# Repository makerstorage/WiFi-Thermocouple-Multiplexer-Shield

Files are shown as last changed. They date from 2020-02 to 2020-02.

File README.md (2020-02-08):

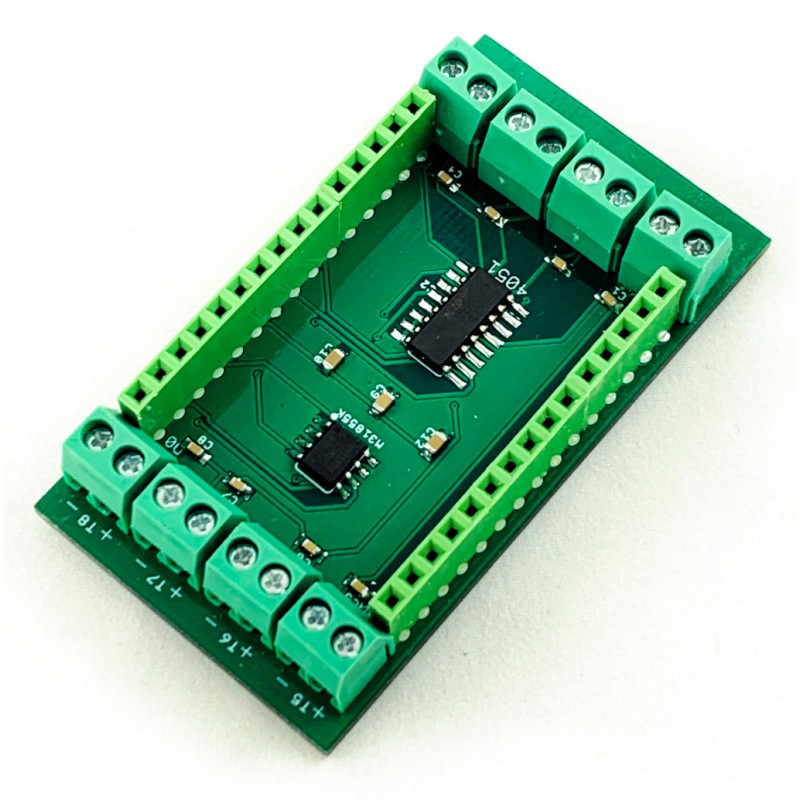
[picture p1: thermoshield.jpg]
WiFi Thermocouple Multiplexer Shield


**WiFi Thermocouple Multiplexer Shield**

For more details, check out the product page at

https://makerstorage.com/index.php?id_product=35&controller=product

MakerStorage invests time and resources providing this open source design, please support MakerStorage and open-source hardware by purchasing products from MakerStorage!

Designed by MakerStorage LLC.

Creative Commons Attribution, Share-Alike license, check https://creativecommons.org/licenses/by-sa/3.0/ for more information All text above must be included in any redistribution

This Shield is designed to easily allow multiple high-temperature readings with an ESP8266 control board. Screw terminals are provided for thermocouple connections.

* Multiplexing seven K-type thermocouples (Can read all sensors under a second)
* Wifi capability (example firmware for local server and Amazon AWS IoT)
* Suitable for only Lolin models of ESP8266 (27mm between headers)
* Onboard Max31855KASA  Cold-Junction Compensated Thermocouple-to-Digital Converter
* Works with K type thermocouples
-200°C to +1350°C output in 0.25 degree increments - note that K thermocouples have about ±2°C to ±6°C accuracy

**Areas to use:**

* Automotive – Engine, Exhaust and Brake temperatures

* Ovens, Furnaces, and Kilns

* Freezer or Cryogenic monitoring

* Chemical Processes

* IoT applications like Multi-Zone Temperature Monitoring, Data Acquisition or Logging Systems

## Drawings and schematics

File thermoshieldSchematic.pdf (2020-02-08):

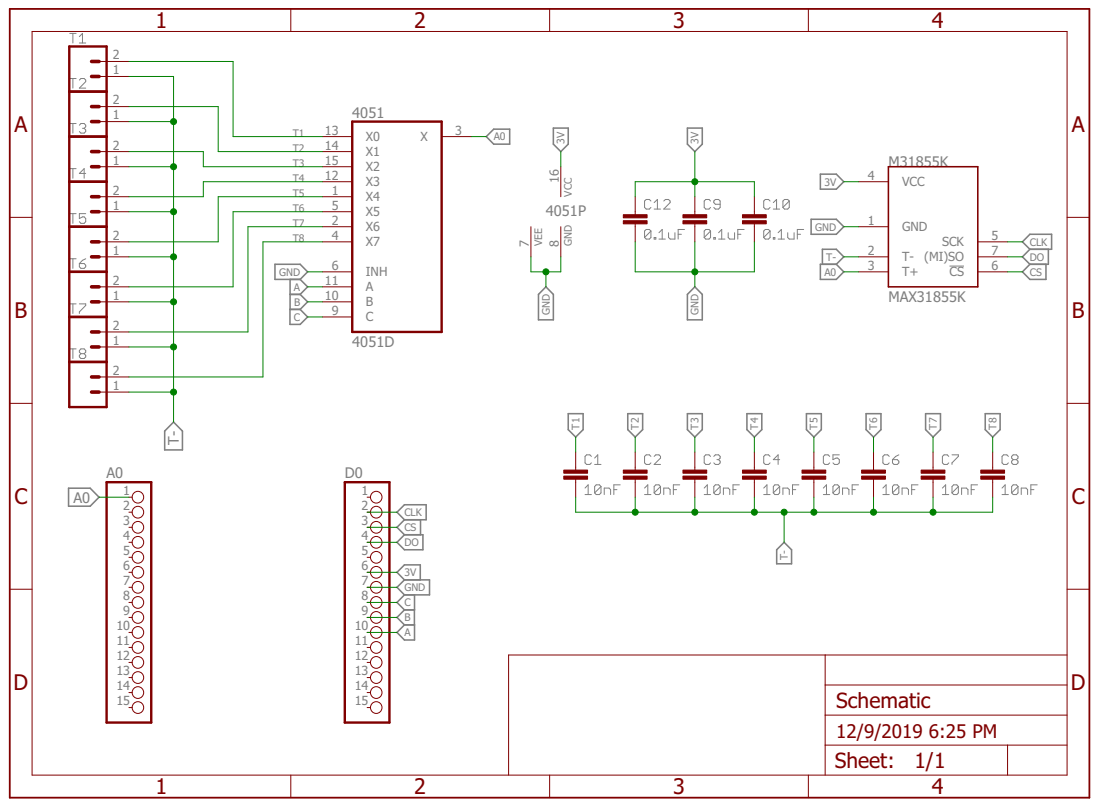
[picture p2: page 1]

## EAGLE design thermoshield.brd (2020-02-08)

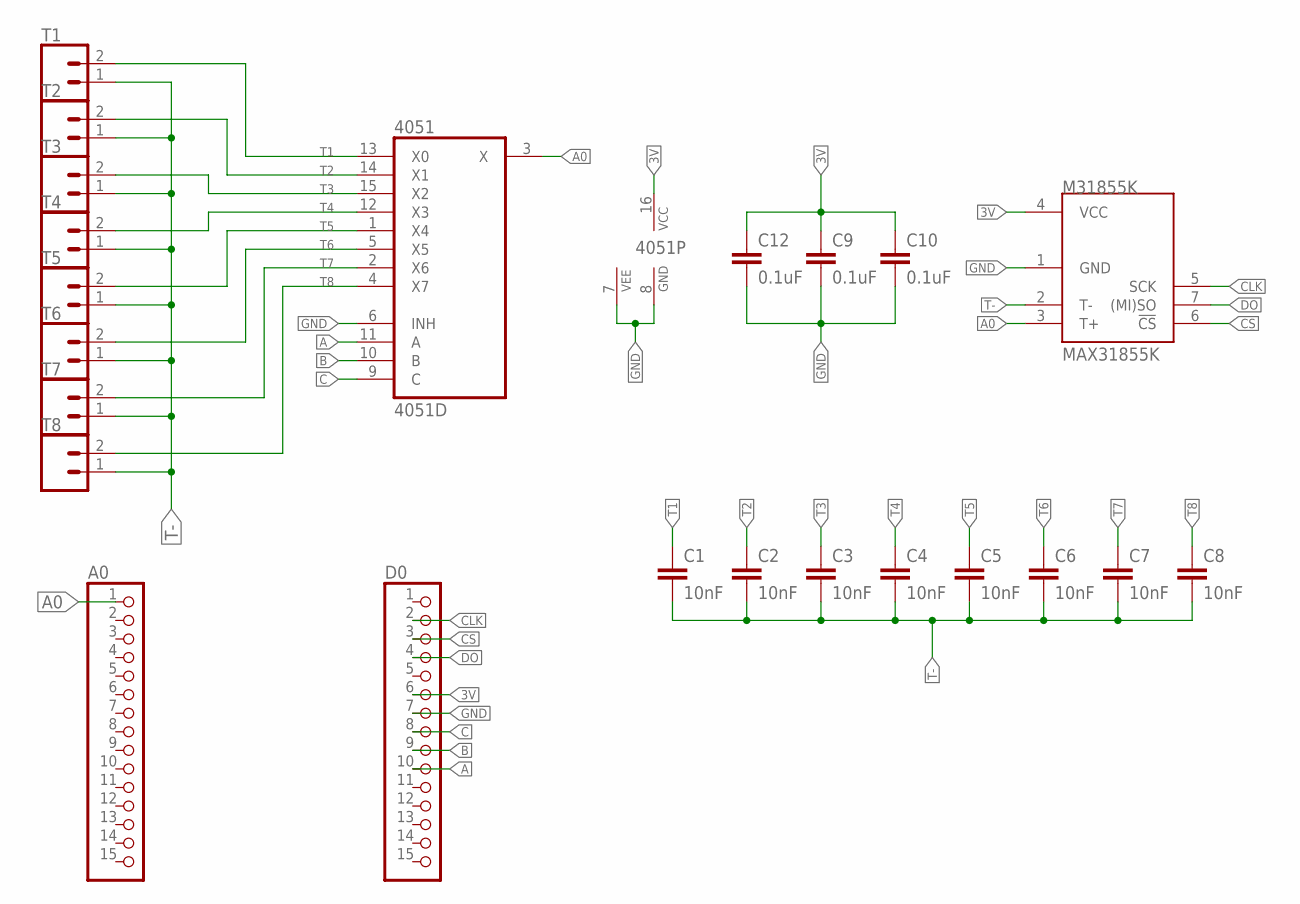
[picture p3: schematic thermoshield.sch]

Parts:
4051: 4051D; SO16
A0: PINHD-1X15; 1X15
C1, C2, C3, C4, C5, C6, C7, C8: 10nF; 0603
C9, C10, C12: 0.1uF; 0603
D0: PINHD-1X15; 1X15
M31855K: MAX31855K; SO08
T1, T2, T3, T4, T5, T6, T7, T8: CONN_023.5MM-NO_SILK; SCREWTERMINAL-3.5MM-2-NS

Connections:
3V: 4051.16 (VCC), C9.1, C10.1, C12.1, D0.6, M31855K.4 (VCC)
A: 4051.11 (A), D0.10
A0: 4051.3 (X), A0.1, M31855K.3 (T+)
B: 4051.10 (B), D0.9
C: 4051.9 (C), D0.8
CLK: D0.2, M31855K.5 (SCK)
CS: D0.3, M31855K.6 (!CS)
DO: D0.4, M31855K.7 ((MI)SO)
GND: 4051.6 (INH), 4051.7 (VEE), 4051.8 (GND), C9.2, C10.2, C12.2, D0.7, M31855K.1 (GND)
T1: 4051.13 (X0), C1.1, T1.2
T2: 4051.14 (X1), C2.1, T2.2
T3: 4051.15 (X2), C3.1, T3.2
T4: 4051.12 (X3), C4.1, T4.2
T5: 4051.1 (X4), C5.1, T5.2
T6: 4051.5 (X5), C6.1, T6.2
T7: 4051.2 (X6), C7.1, T7.2
T8: 4051.4 (X7), C8.1, T8.2
T-: C1.2, C2.2, C3.2, C4.2, C5.2, C6.2, C7.2, C8.2, M31855K.2 (T-), T1.1, T2.1, T3.1, T4.1, T5.1, T6.1, T7.1, T8.1

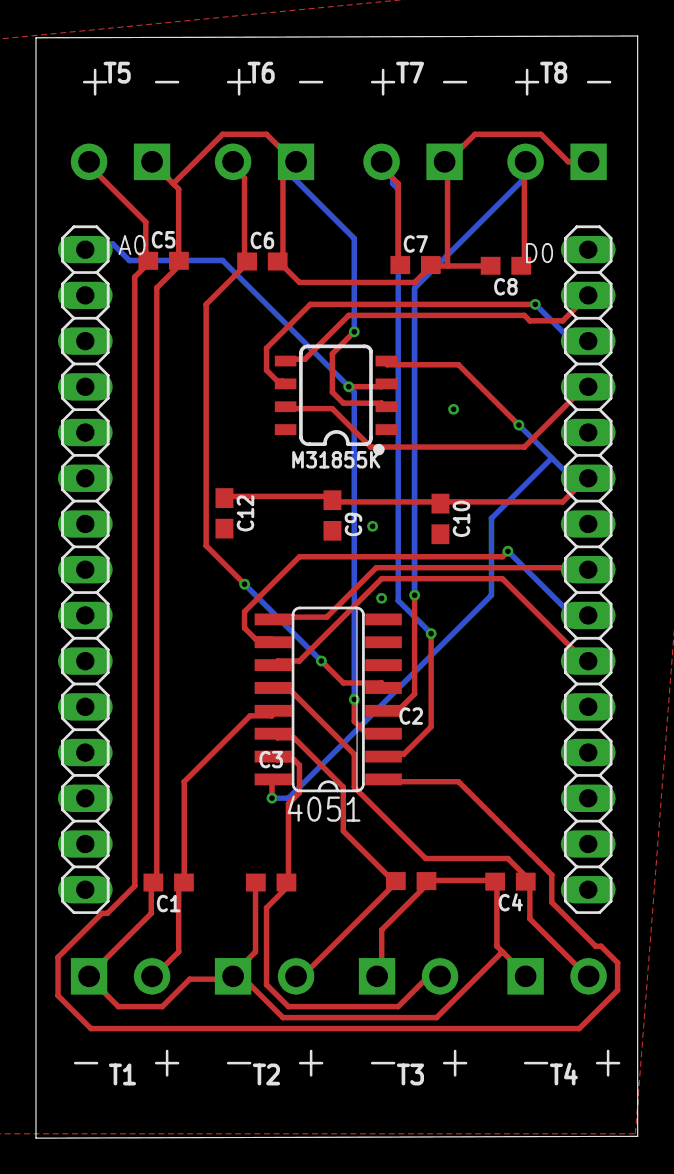
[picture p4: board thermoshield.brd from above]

Board: 2 copper layers, 33.4 x 61.2 mm, 23 parts (0 on the bottom side), 18 nets.

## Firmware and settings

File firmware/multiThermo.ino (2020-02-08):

#include <SPI.h>
#include "Adafruit_MAX31855.h"

#include <Arduino.h>
#include <ESP8266WiFi.h>
#include <ESPAsyncTCP.h>
#include <ESPAsyncWebServer.h>
#include <ESPDash.h>


AsyncWebServer server(80);

const char* ssid = "Tilgin-4sATNx42WS4H"; // Your WiFi SSID
const char* password = "AKpQwcUhvJ6Sk";// Your WiFi Password



#define MAXDO   D3
#define MAXCS   D2
#define MAXCLK  D1
Adafruit_MAX31855 thermocouple(MAXCLK, MAXCS, MAXDO);
const byte common = A0;  // where the multiplexer in/out port is connected

// the multiplexer address select lines (A/B/C)
const byte addressA = D7; // low-order bit
const byte addressB = D6;
const byte addressC = D5; // high-order bit



void setup ()
{
  Serial.begin (115200);
  Serial.println ("Starting multiplexer test ...");
  pinMode (addressA, OUTPUT);
  pinMode (addressB, OUTPUT);
  pinMode (addressC, OUTPUT);

  while (!Serial) delay(1); // wait for Serial on Leonardo/Zero, etc

  Serial.println("MAX31855 test");
  // wait for MAX chip to stabilize
  delay(1);
 
    WiFi.mode(WIFI_STA);
    WiFi.begin(ssid, password);
    if (WiFi.waitForConnectResult() != WL_CONNECTED) {
        Serial.printf("WiFi Failed!\n");
        return;
    }
    Serial.print("IP Address: ");
    Serial.println(WiFi.localIP());
    
    ESPDash.init(server);   // Initiate ESPDash and attach your Async webserver instance
    // Add Respective Cards
    ESPDash.addTemperatureCard("temp2", "Temperature Card 1",0);
    ESPDash.addTemperatureCard("temp3", "Temperature Card 2", 0);
    ESPDash.addTemperatureCard("temp4", "Temperature Card 3", 0);
    ESPDash.addTemperatureCard("temp5", "Temperature Card 4", 0);
    ESPDash.addTemperatureCard("temp6", "Temperature Card 5", 0);
    ESPDash.addTemperatureCard("temp7", "Temperature Card 6", 0);
    ESPDash.addTemperatureCard("temp8", "Temperature Card 7", 0);
    ESPDash.addTemperatureCard("temp1", "Temperature Card 8", 0);

    server.begin();
  
}  // end of setup

int readSensor (const byte which)
{
  // select correct MUX channel
  digitalWrite (addressA, (which & 1) ? HIGH : LOW);  // low-order bit
  digitalWrite (addressB, (which & 2) ? HIGH : LOW);
  digitalWrite (addressC, (which & 4) ? HIGH : LOW);  // high-order bit
  // now read the sensor
  double c = thermocouple.readCelsius();

  if (isnan(c)) {
         Serial.println("Something wrong with thermocouple! or no thermocouple");
         return -1;
  }

  return c;
       
}  // end of readSensor

void loop ()
{ 
  

    for (int i = 0; i <8; i++)
    {  
       double c = readSensor(i);    


       if(i==0){
        ESPDash.updateTemperatureCard("temp1", c);  
        }
       else if(i==1){
        ESPDash.updateTemperatureCard("temp2",c); 
        }
        else if(i==2){
        ESPDash.updateTemperatureCard("temp3",c);  
        }
        else if(i==3){
        ESPDash.updateTemperatureCard("temp4",c);  
        }
        else if(i==4){
        ESPDash.updateTemperatureCard("temp5",c);  
        }
        else if(i==5){
        ESPDash.updateTemperatureCard("temp6",c); 
        }
        else if(i==6){
        ESPDash.updateTemperatureCard("temp7",c); 
        }
        else if(i==7){
        ESPDash.updateTemperatureCard("temp8",c); 
        }
       
        delay(100);
    }//for

  
}  // end of loop

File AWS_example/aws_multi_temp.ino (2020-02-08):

/*Developed by M V Subrahmanyam - https://www.linkedin.com/in/veera-subrahmanyam-mediboina-b63997145/
Project: AWS | NodeMCU ESP32 Tutorials
Electronics Innovation - www.electronicsinnovation.com

GitHub - https://github.com/VeeruSubbuAmi
YouTube - http://bit.ly/Electronics_Innovation

Upload date: 07 October 2019

AWS Iot Core

This example needs https://github.com/esp8266/arduino-esp8266fs-plugin

It connects to AWS IoT server then:
- publishes "hello world" to the topic "outTopic" every two seconds
- subscribes to the topic "inTopic", printing out any messages
*/

#include <SPI.h>
#include "Adafruit_MAX31855.h"


#include "FS.h"

#include <ESP8266WiFi.h>

#include <PubSubClient.h>

#include <NTPClient.h>

#include <WiFiUdp.h>

// Update these with values suitable for your network.

const char * ssid = "Tilgin-4sATNx42WS4H"; // Your WiFi SSID
const char * password = "AKpQwcUhvJ6Sk"; // Your WiFi Password


#define MAXDO   D3
#define MAXCS   D2
#define MAXCLK  D1
Adafruit_MAX31855 thermocouple(MAXCLK, MAXCS, MAXDO);
const byte common = A0;  // where the multiplexer in/out port is connected

// the multiplexer address select lines (A/B/C)
const byte addressA = D7; // low-order bit
const byte addressB = D6;
const byte addressC = D5; // high-order bit



WiFiUDP ntpUDP;
NTPClient timeClient(ntpUDP, "pool.ntp.org");

const char * AWS_endpoint = "ad788dbyue7l5-ats.iot.us-east-1.amazonaws.com"; //MQTT broker ip

void callback(char * topic, byte * payload, unsigned int length) {
  Serial.print("Message arrived [");
  Serial.print(topic);
  Serial.print("] ");
  for (int i = 0; i < length; i++) {
    Serial.print((char) payload[i]);
  }
  Serial.println();

}
WiFiClientSecure espClient;
PubSubClient client(AWS_endpoint, 8883, callback, espClient); //set MQTT port number to 8883 as per //standard
long lastMsg = 0;
char msg[150];
int value = 0;

void setup_wifi() {

  delay(10);
  // We start by connecting to a WiFi network
  espClient.setBufferSizes(512, 512);
  Serial.println();
  Serial.print("Connecting to ");
  Serial.println(ssid);

  WiFi.begin(ssid, password);

  while (WiFi.status() != WL_CONNECTED) {
    delay(500);
    Serial.print(".");
  }

  Serial.println("");
  Serial.println("WiFi connected");
  Serial.println("IP address: ");
  Serial.println(WiFi.localIP());

  timeClient.begin();
  while (!timeClient.update()) {
    timeClient.forceUpdate();
  }

  espClient.setX509Time(timeClient.getEpochTime());

}

void reconnect() {
  // Loop until we're reconnected
  while (!client.connected()) {
    Serial.print("Attempting MQTT connection...");
    // Attempt to connect
    if (client.connect("ESPthing")) {
      Serial.println("connected");
      // Once connected, publish an announcement...
      client.publish("outTopic", "{\"message\": \"yeah connected\"}");
      // ... and resubscribe
      client.subscribe("inTopic");
    } else {
      Serial.print("failed, rc=");
      Serial.print(client.state());
      Serial.println(" try again in 5 seconds");

      char buf[256];
      espClient.getLastSSLError(buf, 256);
      Serial.print("WiFiClientSecure SSL error: ");
      Serial.println(buf);

      // Wait 5 seconds before retrying
      delay(5000);
    }
  }
}


int readSensor (const byte which)
{
  // select correct MUX channel
  digitalWrite (addressA, (which & 1) ? HIGH : LOW);  // low-order bit
  digitalWrite (addressB, (which & 2) ? HIGH : LOW);
  digitalWrite (addressC, (which & 4) ? HIGH : LOW);  // high-order bit
  // now read the sensor
  double c = thermocouple.readCelsius();

  if (isnan(c)) {
        // Serial.println("Something wrong with thermocouple! or no thermocouple");
         return -1;
  }

  return c;
       
}  // end of readSensor


void setup() {

  Serial.begin(115200);
  Serial.setDebugOutput(true);
  // initialize digital pin LED_BUILTIN as an output.
  pinMode(LED_BUILTIN, OUTPUT);


  Serial.println ("Starting multiplexer test ...");
  pinMode (addressA, OUTPUT);
  pinMode (addressB, OUTPUT);
  pinMode (addressC, OUTPUT);


  
  setup_wifi();
  delay(1000);
  if (!SPIFFS.begin()) {
    Serial.println("Failed to mount file system");
    return;
  }

  Serial.print("Heap: ");
  Serial.println(ESP.getFreeHeap());

  // Load certificate file
  File cert = SPIFFS.open("/cert.der", "r"); //replace cert.crt eith your uploaded file name
  if (!cert) {
    Serial.println("Failed to open cert file");
  } else
    Serial.println("Success to open cert file");

  delay(1000);

  if (espClient.loadCertificate(cert))
    Serial.println("cert loaded");
  else
    Serial.println("cert not loaded");

  // Load private key file
  File private_key = SPIFFS.open("/private.der", "r"); //replace private eith your uploaded file name
  if (!private_key) {
    Serial.println("Failed to open private cert file");
  } else
    Serial.println("Success to open private cert file");

  delay(1000);

  if (espClient.loadPrivateKey(private_key))
    Serial.println("private key loaded");
  else
    Serial.println("private key not loaded");

  // Load CA file
  File ca = SPIFFS.open("/ca.der", "r"); //replace ca eith your uploaded file name
  if (!ca) {
    Serial.println("Failed to open ca ");
  } else
    Serial.println("Success to open ca");

  delay(1000);

  if (espClient.loadCACert(ca))
    Serial.println("ca loaded");
  else
    Serial.println("ca failed");

  Serial.print("Heap: ");
  Serial.println(ESP.getFreeHeap());
}

void loop() {

int temp1,temp2,temp3,temp4,temp5,temp6,temp7,temp8;

//  {"state": {"reported" : {"color" : { "r" :255, "g": 255, "b": 0 } }}}  



    
       temp1 = readSensor(0);  
       delay(100);
       temp2 = readSensor(1);  
       delay(100);
       temp3 = readSensor(2);  
       delay(100);
       temp4 = readSensor(3);  
       delay(100);
       temp5 = readSensor(4);  
       delay(100);
       temp6 = readSensor(5);  
       delay(100);
       temp7 = readSensor(6);  
       delay(100);
       temp8 = readSensor(7);  




 

     

  if (!client.connected()) {
    reconnect();
  }
  client.loop();

  long now = millis();
  if (now - lastMsg > 2000) {
    lastMsg = now;
    ++value;
    snprintf(msg, 150, "{\"temperatures\":{\"t1\":%d,\"t2\":%d,\"t3\":%d,\"t4\":%d,\"t5\":%d,\"t6\":%d,\"t7\":%d,\"t8\":%d}}", temp1,temp2,temp3,temp4,temp5,temp6,temp7,temp8);

    Serial.print("Publish message: ");
    Serial.println(msg);
    client.publish("outTopic", msg);
    Serial.print("Heap: ");
    Serial.println(ESP.getFreeHeap()); //Low heap can cause problems
  }
  digitalWrite(LED_BUILTIN, HIGH); // turn the LED on (HIGH is the voltage level)
  delay(100); // wait for a second
  digitalWrite(LED_BUILTIN, LOW); // turn the LED off by making the voltage LOW
  delay(100); // wait for a second
}

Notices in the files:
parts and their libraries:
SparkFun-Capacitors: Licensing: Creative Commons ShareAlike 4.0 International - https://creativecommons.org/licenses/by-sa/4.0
